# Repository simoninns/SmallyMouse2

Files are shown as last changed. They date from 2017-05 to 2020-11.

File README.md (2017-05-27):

## Synopsis

SmallyMouse2 is the AT90USB1287 firmware source code and KiCAD schematic/PCB design for the SmallyMouse2 project.

## Motivation

SmallyMouse2 is a project that creates a USB mouse adaptor for retro computers that use quadrature mouse input including the Acorn BBC Micro, Acorn Master series, Commodore Amiga, Atari ST, busmouse compatible computers and many more.  SmallyMouse2 provides both a generic mouse output header (for attaching mouse to retro computer cables) and an IDC connector suitable for use with Acorn 8-bit user-ports.  SmallyMouse2 also features a configurable quadrature rate limiter that prevents VIA overrun when in use with slower 8-bit machines.

SmallyMouse2 supports both JTAG and USB bootloader programming.  The AT90USB1287 is pre-programmed by Atmel with the (FLIP) DFU bootloader; this bootloader is recognised by Atmel Studio as a programming device and can be used to flash the firmware to the board.

## Installation

Note: This is an Atmel Studio 7 project that can be loaded and compiled by the IDE

Please see http://www.waitingforfriday.com/?p=827 for detailed documentation about SmallyMouse2

## Author

SmallyMouse2 is written and maintained by Simon Inns.

## License (Software)

    SmallyMouse2 is free software: you can redistribute it and/or modify
    it under the terms of the GNU General Public License as published by
    the Free Software Foundation, either version 3 of the License, or
    (at your option) any later version.

    SmallyMouse2 is distributed in the hope that it will be useful,
    but WITHOUT ANY WARRANTY; without even the implied warranty of
    MERCHANTABILITY or FITNESS FOR A PARTICULAR PURPOSE.  See the
    GNU General Public License for more details.

    You should have received a copy of the GNU General Public License
    along with SmallyMouse2. If not, see <http://www.gnu.org/licenses/>.

## License (Hardware)

Both the schematic and the PCB design of SmallyMouse2 (i.e. the KiCAD project and files) are covered by a Creative Commons license; as with the software you are welcome (and encouraged!) to extend, re-spin and otherwise use and modify the design as allowed by the license.  However; under the terms of the Attribution-ShareAlike 4.0 International (CC BY-SA 4.0) license you are required to release your design (or redesign) under the same license.  For details of the licensing requirements please see <https://creativecommons.org/licenses/by-sa/4.0/>

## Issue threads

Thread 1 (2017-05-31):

Spurious button presses on Acorn BBC Master

simoninns, 2017-05-31:
The device initialises with all three mouse buttons in the 'low' state.  Once the first USB report is received the buttons go into the 'high' state (since the mouse buttons are active low).  This causes multiple button presses to be received until the mouse is moved for the first time.  The initial state of the button signals should be high to prevent this.

simoninns, 2017-05-31:
Fixed and tested in last commit.

Closed 2017-05-31.

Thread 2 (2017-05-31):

Slow movement sometimes causes inverse quadrature movement

simoninns, 2017-05-31:
Moving the mouse very (very) slowly can sometimes cause inverse motion.  Observed on a 32-bit Acorn A440/1 machine (host-powered)

simoninns, 2017-05-31:
Fixed and tested in last commit.

Closed 2017-05-31.

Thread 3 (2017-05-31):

Which retro computers have been tested against the v1.1 release

simoninns, 2017-05-31:
Which retro computers are tested and confirmed as working with the v1.1 firmware release of SmallyMouse2?

simoninns, 2017-05-31:
The following retro computers are confirmed as working correctly with the v1.1 release of SmallyMouse2 so far:

Acorn BBC Micro Model B
Acorn Master Turbo
Acorn Archimedes A440/1
Acorn RISC PC 600

simoninns, 2017-06-04:
Tested and working with a Commodore Amiga A600.  Cable details soon.

simoninns, 2017-06-05:
Commodore Amiga A600 now confirmed (diagram added to project page).  Atari 520ST also confirmed (with diagram) - Testing submitted by Bas of BetaGamma Computing

simoninns, 2017-06-20:
Sinclair PC200 tested and confirmed.  Note from user:

Yes no problem. The PC200, Amstrad PC20 and some early Amstrad PCs have the opposite connector gender to the norm so it may be worth mentioning that.
1. X1
2. X2
3. Y1
4. Y2
5. n/c
6. LB
7. 5v
8. GND
9. RB

I also use Olivetti Prodest PC1 but have not confirmed SmallyMouse2 with it yet.
1. RB
2. LB
3. X1
4. Y2
5. 5v
6. Y1
7. X2
8. GND
9. GND (needed, or the PC1 assumes a joystick is connected).

simoninns, 2017-06-20:
Confirmed by a user to work with Acorn A3010 (same pin out as A440/1)

simoninns, 2018-08-26:
This issue is no longer required.

Closed 2018-08-26.

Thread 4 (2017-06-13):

Add USB joystick support?

simoninns, 2017-06-13:
It should be possible to add USB joystick support; most retro computers place the axis movement on the same pins as the USB mouse quadrature (X1, X2, Y1 and Y2) and use the mouse button inputs for the fire switches.

Firmware would need to be enhanced to support both mouse and gamepad HID and auto-switch depending on the connected USB device.

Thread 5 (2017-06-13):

Add report based HID mouse including scroll wheel support?

simoninns, 2017-06-13:
It should be possible to add scrollwheel support by outputting the scroll wheel quadrature between the current mouse X and Y outputs.  On the Amiga (using the wheelbusmouse software in workbench) this seems to be supported by outputting the horizontal scroll wheel on X1 and Y1 and the vertical scroll wheel on X2 and Y2 (although I haven't found any clear documentation). It's not clear from the existing (Amiga) software implementations how this is done right now (so the existing drivers may not support it).

The down-side to scroll wheel support is that the firmware cannot use the (very universal) boot-protocol for communicating with the mouse and must use the full report interface instead.  Some preliminary testing has shown this can be problematic since USB mice are not always really USB mice... For example the Logitech unifying receiver mice start in a standard mouse boot-protocol but do not support the standard reports-based communication (i.e. they are not really USB mice).  This could be very confusing to users as certain mice may not work.

It might be possible to solve this by using a fall-back mechanism where the firmware drops back to the boot-protocol if report based enumeration fails.  Needs some more experimentation to see if LUFA can be made to support such logic.

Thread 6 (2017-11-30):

Amiga 1200 doesn't detect right mouse button press

Septercius, 2017-11-30:
I'm trying to get the SM2 to work with an Amiga 1200 (revision 2B motherboard).  The interface does not detect a right mouse button click (left button and movement are fine).  Using the same setup on an Atari ST (swapping the X2/Y2 over) works without problem.

Using a multimeter, I tested the change in voltage that happens when a mouse button is pressed.  For the left button, the reading goes all the way down to 0V (from 5V).  For the right button, it goes to 0.3V and hovers around there.  If I disconnect the interface from the computer, the voltage does go to 0V when the button is pressed.

It seems that certain Amigas have this problem with other USB mouse adapters:

http://www.amibay.com/showthread.php?53905-Amiga-1200-USB-Mouse-adapter-No-Right-Mouse-button

Certain adapters claim to solve the issue (though it's not stated how):

https://www.ebay.co.uk/itm/MKIV-Amiga-USB-mouse-adapter-RIGHT-MOUSE-BUTTON-FIX/121715285463

Some people suggest that you need an external transistor somewhere:

http://eab.abime.net/showthread.php?t=64460

Is there a fix that can be made (e.g. by building a small circuit sitting between SM2 and computer) that will resolve this?

simoninns, 2017-11-30:
That's odd (very technical response, I know :) )...  Well, since the microcontroller is pulling up the lines to 5Vs it is most likely caused by the level not dropping all the way to 0V when the button is 'pressed' - this could only be caused by a very poor design in the host computer itself.  Simply placing a 4K7 resistor between the button signal and ground should cure the problem (4.7Kohms should be high enough to do the trick without 'straining' the internal pull-up).

If the BBC micro header is unpopulated, you could place the resistor there; otherwise you could solder it to the underside of the board (make sure the leads are insulated and don't cause any shorts).

Can you try this and see if it works?  If so please report back so I can update the project information and, thanks for reporting this!

Septercius, 2017-11-30:
Thanks for the response!  I'm currently using the 10-pin header, not the Beeb header.  The 5V pin and the 0V next to it are connected to a 5V PSU (2A, I think).  The rest of the pins are connected to a cable that leads to the standard 9-pin port on the back of the computer.  Just to be absolutely sure: I should leave this as it is and place the resistor in parallel, across the RB and 0V lines?  I've attached (I hope) a quick mock-up schematic that illustrates what I think I need to do.  Could you confirm I'm on the right track, please?  (I'd prefer not to blow anything up!).

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

simoninns, 2017-11-30:
Exactly right.  The same pins (RB and 0V) are exposed both on the 10-pin header and the 2 row IDC header for the BBC micro; if you simply trace the connections (using your multimeter) you could simply hook the resistor up using the holes for the IDC (but how you connect it isn't important, as long as it's between the RB and 0Vs) - it was just a suggestion.

Septercius, 2017-12-01:
Unfortunately wiring up the 4.7K resistor across the RB and 0V pins didn't make any difference.  The voltages were still 5V (button released) and 0.3V (button pressed).  I checked the circuit by touching both legs of the resistor together (I'd wired it in using some probes) and the computer acted as if the button was held down.

I also tried the next size up of resistor that I could find - 10K: same result.

simoninns, 2017-12-01:
Is there an accurate schematic of the motherboard for the version of Amiga you have?  If you could point me to it perhaps I can figure out what's going on.  There has to be a reason for it not working like this and, if I can figure that out, I could most probably suggest a better workaround.

Septercius, 2017-12-01:
There's some here:

http://www.amigawiki.de/doku.php?id=en:service:schematics

My motherboard is a revision 2B, so presumably it's version 2 of the schematic.

simoninns, 2017-12-02:
Pin 9 of the DSUB (RB) is connected to P0Y/P1Y of the 'PAULA' chip.  Since these are market 'POT0Y and POT1Y' it's safe to assume the chip is acting as an ADC.  The 'middle' button is connected the same way (although I would presume this isn't in use - but it would be failing in the same way).  All of the other lines are connected via a 74LS166 (an 8-bit shift register) which explains the difference.

The software must be expecting the ADC to read a very low value which is basically a bug in the mouse driver...  it should follow the TTL rules (anything below 0.8V should be considered a zero).

I'll have a look at how to solve this and post back.

simoninns, 2017-12-02:
The best thing I can think of (and I have no way to test as I don't have any Amigas) is to use a non-inverting voltage follower on the RB pin.  You can form this circuit with 2 resistors and a transistor (I think a normal small signal NPN will do it, but a MOSFET would provide more range).  If you could try the following circuit it should solve the issue:

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

Septercius, 2017-12-02:
I'll give it a whirl and see what happens, though I'll need to order some bits first.

Looking at the RS web site, there are lots of different BC547 transistors out there:

https://uk.rs-online.com/web/c/semiconductors/discrete-semiconductors/bipolar-transistors/?searchTerm=bc547

Does it matter which one I use?  The main difference I can spot (other than physical size) is in "Minimum DC Current Gain" (whatever that means).

simoninns, 2017-12-02:
The transistor probably doesn't matter too much as long as it's NPN.  I'd go for the 547B, although if you have a BC337 handy, it would probably work too.  Although the configuration is a 'voltage follower' the input to the base of the transistor is either 0V or 5V, so it's just swinging from min to max, so the details of the transistors finer qualities shouldn't make too much difference.

Basically the circuit should work like this:

If RB_in is 0V power cannot flow from the collector (pin 1) to the emitter (pin 3) of the transistor so the circuit takes the path of least resistance to ground.  If RB_out is 5V then power flows through the transistor making RB_out 5Vs.

The 10K resistor acts to limit the current draw from the microcontroller and the 4K7 pulls RB_out to 0V when the transistor is 'closed'.

The downside of a transistor is that it's not a 'perfect' switch, so it will never be truly 5V or 0Vs... the better the transistor - the closer it gets to being a switch (with MOSFET transistors being best at this).  Since the resistor is on the ground-side of the transistor it should present a much better 'ground' to the Amiga's ADC than the microcontroller pin... Thereby solving the issue...  (I hope! :) )

Septercius, 2017-12-16:
I finally found time to try the suggested circuit.  The 5V and 0V lines are connected to a separate 5V PSU.

The voltage is 4.44V if the right mouse button is pressed; if I press the button, it reduces to 3.85V, not 0V.  I have checked my circuit and can't see anything amiss.  If I connect everything as it was before (i.e. without the circuit), I see the previous behaviour (5V on not pressed, 0.3V on pressed) and all the other mouse functions work correctly.

simoninns, 2017-12-16:
Can you try increasing the value of the 4K7 resistor (10K, 100K, 1M) and see what effect it has?  If nothing works let me know and I'll try to find some time to set it up on the breadboard and look at what's going on.

snnsyhn, 2019-09-06:
Thank you.
I replaced the PAULA and the right mouse button problem solved.

simoninns, 2019-09-06:
Sounds like the root cause of this issue is identified; and the SM2 is functioning correctly.  Thanks for the feedback, I'll close this issue for now then,

gianlucarenzi, 2019-09-06:
I changed PAULA too, and it worked for me. As soon the board was in the customer's side, the problem persists. I had no time to check it out again... sorry. But I suppose something weird who breaks PAULA from the mouse port. I dunno.

ChuckyGang, 2020-01-31:
https://www.tsb.space/knowledge-base/amiga-1200-right-mousebutton-does-not-work/

JaneDoe649, 2020-07-19:
I had the same issue: the right mouse button did not respond when using the Smally Mouse. Apparently Paula's internal pull up resistor has a very low value which induces a current of almost 20mA when the level on Pot0X is set at 0V. Apparently the microcontroller cannot absorb it which causes too much voltage at the input of Paula to detect level 0.

I solved the problem by connecting the PC6 and PC7 pins together and modifying the declaration of the right button like this: #define RB ((1 << 6) | (1 << 7))

When the right button is pressed the two lines PC6 and PC7 drain the current and level 0 is well detected by Paula.

Closed 2019-09-06.

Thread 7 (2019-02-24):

Atari ST some problems

pazuzu72, 2019-02-24:
Hello everyone, on the **Amiga** it works very well (**500**, **600**, **1200**). On **Atari 1040 STE** (the only one I have available) has some problems. If I move the mouse too fast, it does not seem to be behind the speed and resets the pointer arrow position. Even setting the jumper on **slow**.

Can someone confirm or not the same problem?

dh219, 2019-12-06:
Yes, I can confirm. The ST range seems particularly sensitive to too high stimulus -- I can reproduce a similar effect on my 90s ball mouse by spinning the rollers with my finger.

The same problem is very hard to replicate on my Archie A3000, so I think it might be an Atari phenomenon and might explain why my TOM2 has such a low max speed in ST mode.

I'll try to have a dig in the firmware and see if I can improve it a bit.

dh219, 2019-12-31:
I've made some changes to my fork of the firmware that I think overcomes this issue -- firstly it looks like the Atari range can't handle polling rates over about 500Hz. Setting the rate limit to 500 solves the jumping cursor issue.

Also I've added a DPI scaler parameter that will basically scale down the effective DPI of the mouse as modern mice are far too high by default. I find a setting of 2 or 3 is good for modern 'slow' mice. 4 is about right for faster ones.

If you have the means to recompile and flash the firmware, have a look on my fork:- https://github.com/dh219/SmallyMouse2

pazuzu72, 2020-01-05:
Great! I have tried your version. I set the variable to 3 and it works great on 8 bit atari too. It is also better on amiga. Thank you :-)

simoninns, 2020-02-08:
In the V1.2 release I have added an additional 'jumper' configuration to turn on DPI divider support (which, by default divides by 2).  I have also lowered the quadrature limit when the SLOW header is used.  The DPI divider jumper should be placed between D7 and 0V on the expansion header which was previously a general purpose GPIO pin.

Closed 2020-02-08.

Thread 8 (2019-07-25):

At least RMB need to be open collector output

TzOk83, 2019-07-25:
Actually all outputs should be open-collector type, but on Atari ST the right mouse button is a must, as in other case it will conflict with a joystick fire button (they are shorted together on Atari side).

simoninns, 2019-07-26:
Can you elaborate more about the use-case here as I'm not really sure what your issue description is trying to solve.  This can't be a 'must' since there are many people using SM2 with Atari STs and it works.  What is the actual issue you are testing in order to reach your conclusion?

TzOk83, 2019-07-30:
This is a formal requirement of a mouse/joystick port - all outputs should be open-collector type (either in high impedance, or shorted to ground). In most cases it will work with a normal output, but problem will arise when you will try to use mouse on port 0 and joystick on port 1. Right mouse button on port 0 (pin 9) is connected together with a fire button on port 1 (pin 6). All signals are active low, so at idle they are held high (+5V). When you press fire on the joystick, the pin 9 of port 0 is directly shorted to ground, while on the same time SM2 tries to hold this pin high. In most cases it will work, but stressing the PC6 pin over its limits, and unnecessarily drawing over 20mA. Microswitch based joysticks will work fine, but some universal Atari/CPC or game-pads with rubber switches - won't due to high closed switch resistance.

dh219, 2019-12-06:
Can confirm what TzOk83 says. At least on the ST pressing fire on joystick 1 causes a short in the SmallyMouse2 with stock firmware. I've instigated a fix (for buttons only) in my fork. I'm not really familiar enough with Git to know how to submit a change to your repo for that file only. The diff is small and visible here, however, if you're interested: https://github.com/dh219/SmallyMouse2/commit/803f7c1757fec1a24074387a8cf2013e2163f189

Regards.

TzOk83, 2019-12-07:
@dh219 You should have created a Pull Request to the Master branch of the original project in order to integrate your patch with it.

simoninns, 2020-02-08:
In the V1.2 release I have added support for open-collector mouse buttons for all 3 buttons (as it shouldn't have any negative effects on other machines) - I've tested it with a BBC Micro and an Acorn Archimedes and it functions fine.

Closed 2020-02-08.

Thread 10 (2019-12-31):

Small 'direction lag' upon change of mouse movement direction.

dh219, 2019-12-31:
Symptom can be demonstrated on stock firmware:

* Switch to a low screen resolution (not necessary, but makes visualising it easier)

* Slowly move the mouse pointer left, right, up or down.

* Stop

* Slowly move the mouse pointer in the opposition direction, right, left, down or up.

> The initial movement of the mouse will be the first direction rather than the second.

This makes delicate selection difficult -- important in lower resolutions. I can reproduce this on Atari and Acorn hardware.

Can anyone else confirm this? Can anyone suggest where in the firmware to look for this 'direction lag'?

Regards,

DH.

simoninns, 2020-02-08:
This was a very well spotted bug :)  Took me quite a while to work out what was causing it...  Turns out that the quadrature phase was not being reset when the mouse changed direction, so for the tiny part of the phase left over the host computer didn't see the direction change.  In the V1.2 firmware the quadrature phase is reset as soon as there is a change of direction, which solves this issue (at least it does on the Acorn Archimedes A310/1 that I tested it on).

dh219, 2020-05-03:
Hi Simon,

Thanks for looking into this and deploying a proposed fix. Unfortunately the fix appears to be worse than the cure when tested on my Falcon.

With both the divisor (another requested feature added -- thanks) and the rate limiting (now defaulting to 500 -- thanks again) disabled to avoid any cross contamination with other new features, the quadrature output now seems to simply drop a lot of movement at low speed resulting in very strange jerkiness. Very occasionally some directional lag is still seen.

I've been trying to understand the effect the mouseEncoderPhaseX/Y=0 lines should have, but can't see how setting those when there is no movement should fix the original problem. Indeed, commenting them out restores behaviour to that of the 2017 variant, so I can see they're the source of this new behaviour.

From what I can understand, changing mouse direction should just change the direction of the quadrature state rather than starting again from zero, so I'm not sure this is the right place to address the bug.

I've put together a small video demonstrating the effect. Apologies for the mobile-pointing-at-a-screen quality.

[https://youtu.be/rnZ-SXimxc0](url)

simoninns, 2020-07-30:
I've reimplemented the fix in (what I think) is a more logical way.  I don't see any lag on my Archimedes A440/1; can you test the latest git commit @dh219 and let me know if it solves the issues for you?

dh219, 2020-11-08:
> I've reimplemented the fix in (what I think) is a more logical way. I don't see any lag on my Archimedes A440/1; can you test the latest git commit @dh219 and let me know if it solves the issues for you?

Hi @simoninns ,

Apologies for the long delay in getting back to you on this -- I blew up my unit and it's taken me this long to build a new one!

On the face of it, this seems to work beautifully compared to the previous releases. It's obviously more noticeable in lower resolutions so I've done some extensive testing at 320x200 (by playing Lemmings -- the test of champions) and all seems well here.

I don't know if you're interested in collecting known good settings, but FWIW, I found a DPI divisor of 3, a rate limit of 400 and a buffer limit of 400 produces very usable results on the Atari ST range with my set of cheap Amazon laser mice. I haven't tested on my A3000 yet, but that should behave like your A400 and be generally far more forgiving of higher rates.

Many thanks again and sorry for the delayed response.

DH.

Closed 2020-11-08.

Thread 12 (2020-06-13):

When moving mouse very slowly point stops moving.

xwildx, 2020-06-13:
Standard SmallyMouse2 Board
V1.2 Firmware
Amiga 500 Rev5 motherboard
When moving the mouse very slowly the point stops moving. If you speed up mouse movement a little pointer moves normally. This is only a small issue. but the problem becomes much worse when the right mouse button is pushed and held. Making it difficult to select menu items.

xwildx, 2020-06-14:
Did some more testing and found the following:

Commenting out the following 2 lines in the code.
mouseEncoderPhaseX = 0
mouseEncoderPhaseY = 0

Fixes the problem of the mouse stopping while moving very slowly. Of course this reintroduces the directional lag issue reported by dh219. I find this a much less annoying issue.

As for the RB issue. This looks to be something more problematic. I rewired  the MB to pin 9 (RB) input on the Amiga. So I'm using the MB on the mouse as the RB on the Amiga. (ie I swapped Pin 6 and 7 on the universal output connector).

So the MB acts like the RB, as far as the Amiga is concerned. This works normally and mouse movement is not affected when the MB (acting as RB) is pushed and held.
But if I push and hold the actual RB the mouse movement is still affected. Even if I disconnect the RB output from the amiga.

So it's not a problem with my Amiga hardware.

I have also tried a number of different mice. Both wired and wireless. All exhibit the same behaviour.

Maybe a problem with the USB library??

xwildx, 2020-06-18:
I have changed some lines in the code so the MB now outputs on pin 6 port c on the AVR and the RB now outputs on pin 5 of port c.

So now the MB is output to the right mouse button input on the Amiga
and the RB is output to the middle mouse button input on the Amiga
(Basically the same thing I did above but this time i did it in software not hardware)

If the MB is pushed and held it acts as the RB (menu) on the amiga and works fine.
If the RB is pushed and held it acts as the MB (not really used) on the amiga and the mouse movement is affected.

So I looks like the problem is only with the RB.

Could someone confirm this?? If you push and hold the RB on the mouse and slowly move the mouse  at the same time does it make the mouse movement erratic?

I have built 2 SmallyMouse2 boards and both exhibit this behaviour.

simoninns, 2020-06-18:
Thanks for reporting the issue; I don't have an Amiga, but I will test this out once I have the opportunity and see if I can recreate the observed behaviour.

xwildx, 2020-06-19:
Thanks for looking into it. I have done a bit more testing.
I powered the SM2 from a 5V supply plugged in a mouse and connected an oscilloscope to the Y2 output on the universal output connector. Note the SM2 is not connected to my Amiga.

I then tried to move the mouse, as steadily as possible, in the "UP" direction and observed the waveform. While moving the mouse I then pushed the RB.

As you can imagine moving the mouse steadily enough to get a "clean" waveform is difficult. But when I push the RB I can see the waveform change.

From this
_____         _____
|         |        |         |
|         |____|         |____

To This
__                __
|  |                |  |
|  |________|  |________

If the pulse is at  +5V say for 20ms and at 0V for 20ms, when the RB is pushed it changes to about 5ms and 35ms.
So the pulse width is narrowing with the RB pushed but the frequency stays the same.
And the slower you go the narrower the pulses get. But only with the RB pushed. The LB and MB don't have this  problem.
I will try to film this and put a video on youtube over the weekend.
Will post a link when its up.

xwildx, 2020-06-21:
I have put up a short video showing a capture of my oscilloscope. It's a bit hard to see but at about 6 sec I push and hold the RB and you can see the pulses become shorter. Some  are down to about 5ms or so.  This is only one output but it's the same on all 4 outputs. If you pause the video at about 8.5 Sec you can see the short pulses.

At the end of the video there is a small clip showing the mouse movement. About half way up the screen I push the RB and the mouse stops moving.

https://youtu.be/6IHmSAWSCrc

If there is anything else I can so to help let me know.

simoninns, 2020-06-22:
I've confirmed that the right button issue is reproducible and I get the same issue as observed on my test board.

It looks like the slow movement and RB held issues are possibly unrelated (so should be two issue reports), but I'll leave them as one for now.

simoninns, 2020-07-30:
I've pushed a fix which I believe solves the observed problems; can you compile and flash the latest git commit and test?  Please let me know the result @xwildx

xwildx, 2020-08-01:
Flashed the latest commit and have been testing it. Can confirm the slow movement and RB held problems are fixed. Thank you for the effort.

simoninns, 2020-08-01:
Great, I'll put up a new release shortly then.  Thanks for the assistance with testing!

Closed 2020-08-01.

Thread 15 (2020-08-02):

Potential improvements/minor issues

simoninns, 2020-08-02:
(copied from email source)

There's a potential divide by zero.  I could see that causing jerky mouse at low movement rates since the counter will tend towards zero the slower it's moved, so more chances for an exception or whatever that MCU does in that case.

Change line 519:
from: timerTopValue = ((10000 / timerTopValue) / 64) - 1;

to:
if (timerTopValue > 0)
    timerTopValue = ((10000 / timerTopValue) / 64) - 1;
else
    timerTopValue = 155;

Also found another minor bug where it detects a change in direction starting in line 380

if (MouseReport.X > 0 && mouseDirectionX == 0) {
    mouseDistanceX = 0;
    mouseDirectionX = 1;
} else if (MouseReport.X < 0 && mouseDirectionX == 1) {
    mouseDistanceX = 0;
    mouseDirectionX = 0;
} else if (MouseReport.Y > 0 && mouseDirectionY == 0) {
    mouseDistanceY = 0;
    mouseDirectionY = 1;
} else if (MouseReport.Y < 0 && mouseDirectionY == 1) {
    mouseDistanceY = 0;
    mouseDirectionY = 0;
}

This should be split into 2 blocks, otherwise if both axis change direction at the same time the Y axis won't get reversed correctly until the next USB report, causing the Y axis to move wrong/jerky for a short while.

if (MouseReport.X > 0 && mouseDirectionX == 0) {
    mouseDistanceX = 0;
    mouseDirectionX = 1;
} else if (MouseReport.X < 0 && mouseDirectionX == 1) {
    mouseDistanceX = 0;
    mouseDirectionX = 0;
}

 if (MouseReport.Y > 0 && mouseDirectionY == 0) {
    mouseDistanceY = 0;
    mouseDirectionY = 1;
} else if (MouseReport.Y < 0 && mouseDirectionY == 1) {
    mouseDistanceY = 0;
    mouseDirectionY = 0;
}

simoninns, 2020-11-28:
Fixed in master

Closed 2020-11-28.

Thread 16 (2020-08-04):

Add binaries to latest release

tdaede, 2020-08-04:
v1.2 is missing a binary.

FWIW probably only the .hex or .bin files are enough for DFU purposes.

simoninns, 2020-08-04:
I noticed that recently :)  I'm just running through some testing (and there are a couple more pending fixes) ready for a 1.3 release (1.2 had a couple of noticeable bugs for Atari and Amiga users).

When I release 1.3 I will include the .hex and close this issue (just so I don't forget in the meantime).

Thanks for the report!

pazuzu72, 2020-11-09:
Hi, is there any news on version 1.3? I need to make a couple for atari and amiga.

simoninns, 2020-11-28:
V1.3 released including .hex firmware image

Closed 2020-11-28.

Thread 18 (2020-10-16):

Very slow on 8-bit (BBC micro) machine

JasonStonier, 2020-10-16:
Ok, firstly thanks for a great design and for making it open source.

Disclosure - this is the first time I have soldered surface mount, and the first time I've programmed a microcontroller, so a thousand things could be wrong! Built the board up, flashed ok (I think) with Atmel Studio, and installed to a BBC micro with appropriate support ROM.

My board is sub-populated, so without the quadrature header, or the generic header - only the SMT parts, the 2x13 pin box header for bbc - the SLW jumper (closed), and the two uC bootload and reset jumpers (open).

On the beeb, I have to move the mouse -really- slowly to get it to register properly - the SLW jumper makes no difference.

Any pointers on what I should focus on to find the issue? Thanks.

simoninns, 2020-10-17:
It's a pretty simple circuit, so it's likely one of three things.

Firstly check around the AVR chip pin to pin with a multimeter and make sure you have no shorts.

Secondly check the fuse settings of the AVR and make sure they are right and the AVR is running at the correct speed (this is very unlikely to be wrong if the USB mouse is working at all).

Finally check the Beeb... either plug in a known working board/mouse or, if possible, try your SmallyMouse2 in another Beeb.  There can be anything from dirty pins to semi-working buffer ICs in there.

JasonStonier, 2020-10-18:
Thanks for the reply Simon. So, no shorts - checked all that, and also re-flowed the solder and checked every component to ground/AVR pin. the beeb is -unlikey- to be the problem as I have a number of userport devices which all work ok. Without going through the exact pinouts, obviously this isn't definitive but it seems unlikely.

Fuse settings - I have only the most basic knowledge of programming micros - to flash the device I just loaded up your Atmel project in studio 7, compiled it, and flashed it to the chip. Is there any setup which needs to be done to the chip before flashing?

I have a few PCBs and I've just ordered a batch of micros to build them up, so it may turn out to still be my dodgy soldering - I'll let you know.

simoninns, 2020-10-18:
The fuse settings should be fine if you used studio 7.

On the Beeb; there is a very (very) small chance it could be the 6522 VIAs; there are two in the Beeb though, so just swap them over and see (sometimes the GPIOs are fine, but the timers go weird).

Other than that, the most likely thing is some kind of construction error; making another board and comparing is a easy test though since you are already doing that.

JasonStonier, 2020-11-02:
Again, thanks for the replies - made a second board and exactly the same symptoms. All buzzed out ok and no shorts, but still the problem that moving the mouse too fast causes the pointer to reverse direction and get very choppy on screen.  Really strange! I've buzzed the ribbon cable out too, and pin to pin it's fine, so the last remaining thing to check is the 6522s. I've tried with two different mice, but will gather a collection to see if it's some weirdness with especially high DPI or something (I doubt it though, they're both bog standard USB mice) - or the surface I'm using them on (again, doubt it as they work fine in Linux).

JasonStonier, 2020-11-02:
I'm going to hack about with the code a bit to force it into rate limiting regardless of the SLW jumper - might help start to identify where my problem is.

JasonStonier, 2020-11-03:
Spent an hour inexpertly playing with the code (really well-commented code, very readable even for me) - first thing is that the SLW jumper definitely is being recognised by the uC, so I played with the settings for Q_RATELIMIT and Q_BUFFERLIMIT and discovered that my beeb won't sample accurately at a rate above 300Hz. With rate = 300 and buffer = 100 the mouse movement is now working, but physically moving the mouse fast causes the pointer to slow down significantly showing that sample points are being missed. The effect is present at rates down to 200Hz, but below 250Hz the sampling is too slow to represent the mouse movement properly (a fast circle produces a square, for example).

Is this adding evidence to the problem being in the timing of my 6522s?

simoninns, 2020-11-03:
The 6522s in the Beeb are generally in sockets and can be easily swapped.  The best way to test if the 6522s are at fault is to spend 2 minutes swapping them over; just try that and see if the issue goes away - that way you will know if that is the cause of the issue rather than guessing.  If a chip is failing the symptoms can be completely random, so there is no other way to tell for sure.

JasonStonier, 2020-11-05:
Cheers Simon - I will do that next time I have my beeb open (it's in a custom case so not just as easy as taking the lid off). What's interesting is that it needs to be exactly 300Hz: 301Hz exhibits the behaviour, so it doesn't <feel> like a timing fault. Can I ask: when you've done your testing on a beeb, what ROM and software are you using? - I'm using the official AMX ROM amxmse316 and AMXSuperArt as the test bed. Just wondering if it could be a sampling issue in the software, rather than a hardware fault.

simoninns, 2020-11-05:
I've used both AMX ROMs and VFS ROMs during testing... However; if you consider that many hundreds of SmallyMouse2 devices have been made - and many of those are used with Beebs...  It's far more likely to be a fault local to your setup than the software - which is why swapping the 6522s is a good approach.  If this is hard to do, perhaps buying a SM2 from Ebay and testing it on your machine would be another quick way to see where the issue is.

JasonStonier, 2020-11-05:
Of course - totally get that, and I appreciate the level of support you've shown for what is, after all, given away for free :-)  I'm trying to understand the problem, as well as solve it. Thanks.

simoninns, 2020-11-28:
Closing issue; please open a new one if you track the cause of your observations (and it is a bug/something that need investigation)

Closed 2020-11-28.

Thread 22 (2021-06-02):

Accept input from multiple USB mice

Mellified, 2021-06-02:
I have my SmallyMouse2 connected to an Atari Jaguar via a DB9 to DB15 adapter. With the wireless USB dongle for my mouse attached directly to the SmallyMouse2 everything works as expected! However, when connecting through my USB KVM the SmallyMouse2 does not work. I assume this is because there are multiple USB devices connected: 2 mice and 2 keyboards. In Linux and Windows the default behavior when multiple USB HID mice are connected is to sum the inputs and move the cursor accordingly. I'd like to see SmallyMouse2 updated to do the same ideally.

simoninns, 2021-06-03:
Unfortunately acting as a hub and supporting multiple device types is not really practical as the on-board processor doesn't have the support capabilities.  SmallyMouse2 only supports a single USB HID mouse device via the USB port.

Closed 2021-06-03.

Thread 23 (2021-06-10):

fix for A1200 Rev 2B Amiga RMB

kipper2k, 2021-06-10:
After building and testing the smally mouse on Amigas i found that the Rev2B A1200 Amiga RMB did not work. the problem was identified as bad caps and non working Paula. There is someone on Ebay who is selling "fixed" adapters but as far as i can tell he has not released any details on how he done it.

 I believe i have fixed the problem by placing 2 mosfets in cascade from the chip to the RMB input. I will play around with the resistor values and do a little more testing and then i will release the mod here so all can benefit

Sgw32, 2022-10-12:
@kipper2k Thanks for the idea!
Does it work on Amiga 500?

kipper2k, 2022-10-12:
yah, works on all

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

kipper2k, 2023-07-18:
Forgot to add this, it is a render of how it looks on the motherboard.
There is a USB header so people can run a USB cable if they don't want to
use the actual USB plug,. below the Smally is my video Hybrid board which
you break off and an expansion board for IDE so people can mount it
wherever :)

Brian

Closed 2023-11-20.

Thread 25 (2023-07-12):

Use of Smally mouse on an Amiga motherboard

kipper2000, 2023-07-12:
Hi, I am designing an Amiga 500 motherboard and i would like to add the layout of your smally mouse to the motherboard. I have someone screaming at me that i am not allowed to do it. I will not add the chip for it, just the layout and am making the motherboard gerber free to use so people can do thir own boards,

 Can i have permission to add the schematic to the motherboard. A USB mouse is much better than the already mounted serial mouse.

Thanks

kipper2k

simoninns, 2023-07-17:
This is allowed as the board design is CC licensed - you can read about this in the README.md in the main repo.  Provided you are intending on releasing under the same share-alike license, there is nothing to discuss :)

The software is GPL, but as this is only on the AVR itself, it doesn't knock-on to anything else that might be in your project.

If you are not intending on publishing your schematics and board designs under an open license - then it's not allowed.  However, if this is just because you don't want to use sharealike CC and want to use another open license - just let me know what you are planning and I can provide written permission.

(sorry for slow response, I'm on vacation at the moment :) )

kipper2000, 2023-07-18:
Hi Simon,

Hope your holiday  is going well :). Thanks for the reply.  The overall
scope of my project is to design a  new SMD Amiga 500+ motherboard. I built
the first test board back in early 2021 and then priorities shiftd so it
has been shelved ever since.  The current version motherboard itself has
been tested with onboard Gotek, 2MB chip mem and a quadrom option that
allows a user to toggle up to 4 x 512MB Rom images using an Amiga warm
reset (remembering current selected rom on next reboot. There is no issue
using these addons..  The Smally board circuit is on the motherboard also,
(see picture)  I still need to verify the circuit.  1 question for the
outputs to the original mouse port, do i need to put diodes on to protect
the chip in the event someone uses the original mouse port ?

 I am also adding 8MB fastmem and IDE functions so people can use CF card,
SD, and HDD using one of my old designs (based on NedoPC way back in 2015).
I  have found a way to implement 1 of those cheap Chinese wifi/bluetooth
Sony PS2 joysticks. Basically I am trying to give the A500+ all the options
without all the plugins.

 My desire for this board is to release the Gerbers free, and allow people
to build their own. This way they can do the work and I am assuming it
would be considered personal use. I know that people will probably want to
build a few themselves at a profit but if you check ebay etc it is
happening with boards etc that are not supposed to be commercially sold.

I am including your updated Smally schematic that I did with Mike Stirling
(he was the real brain :). It fixes the RMB problem on one of the A1200
version motherboards. I removed the header for the Atari version as
obviously no need on this motherboard

 I will of course give you full credit shown on the motherboard with
description of your choice. and like i said it will be up to the end user
to supply/program the chip. Ultimately I would like to just have the Smally
circuit on the motherboard so people have the choice of whether to use the
serial port or USB.

Thanks for your time, let me know if you need more info and if you are ok
with what I would like to do.

Brian, (kipper2k)

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

simoninns, 2023-07-27:
I would prefer that you followed the CC ShareAlike license rules... the idea is that, just as you take my design and benefit from using it in your design, others can take your design and benefit from using it in theirs.  What you are proposing is freely using and extending my work into something which you then provide closed (gerbers don't count as they are not really possible to manipulate).

Provided you are not-for-profit; I will be flexible and state you have permission to incorporate the schematic from SmallyMouse2 - but please consider using a sharealike design so others can benefit from your work as you are from mine :)

Closed 2023-07-27.

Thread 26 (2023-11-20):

Newlink NLMS-222A USB Mouse not working

simoninns, 2023-11-20:
I got a report from Amiga Kit that the Newlink NLMS-222A wired USB mouse does not work with SmallyMouse2.

Adding this report to track the issue.

simoninns, 2023-12-07:
Linux output when mouse connected:

```
2023-12-07T07:23:56.782703+01:00 sehotitan01 kernel: [159117.006815] usb 1-5: new low-speed USB device number 6 using xhci_hcd
2023-12-07T07:23:56.946602+01:00 sehotitan01 kernel: [159117.170479] usb 1-5: New USB device found, idVendor=1c4f, idProduct=0034, bcdDevice= 1.10
2023-12-07T07:23:56.946619+01:00 sehotitan01 kernel: [159117.170487] usb 1-5: New USB device strings: Mfr=1, Product=2, SerialNumber=0
2023-12-07T07:23:56.946620+01:00 sehotitan01 kernel: [159117.170489] usb 1-5: Product: Usb Mouse
2023-12-07T07:23:56.946621+01:00 sehotitan01 kernel: [159117.170491] usb 1-5: Manufacturer: SIGMACHIP
2023-12-07T07:23:56.962561+01:00 sehotitan01 kernel: [159117.188269] input: SIGMACHIP Usb Mouse as /devices/pci0000:00/0000:00:01.2/0000:02:00.0/0000:03:08.0/0000:06:00.1/usb1/1-5/1-5:1.0/0003:1C4F:0034.000D/input/input32
2023-12-07T07:23:56.962565+01:00 sehotitan01 kernel: [159117.188391] hid-generic 0003:1C4F:0034.000D: input,hidraw8: USB HID v1.10 Mouse [SIGMACHIP Usb Mouse] on usb-0000:06:00.1-5/input0
```

simoninns, 2023-12-07:
IC in use is marked MX8733B and WS31007:

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

simoninns, 2023-12-07:
MX8733B Datasheet:

[MX8733B.pdf](https://github.com/simoninns/SmallyMouse2/files/13599857/MX8733B.pdf)

simoninns, 2023-12-07:
Console output:

```
SmallyMouse2 V1.3 - Serial SmallyMouse2 V1.3 - Serial debug console
(c)2017-2020 Simon Inns
http://www.waitingforfriday.com

Rate limit switch is OFF
DPI divide switch is OFF
USB Device attached
USB Device detached
USB Device attached

Device Enumeration Error!
 -- Error Code 1
 -- Sub Error Code 1
 -- In State 8
USB Device detached
```

simoninns, 2023-12-07:
Looks like the mouse IC is pretty buggy and doesn't like to enumerate... The timeout is currently 1000ms (1 second) - but setting the enumeration timeout to 10 seconds seems to make the device work...

Adding the following parameter to the makefile seems to do the trick:

-DHOST_DEVICE_SETTLE_DELAY_MS=10000

I don't think this is generally good though as it slows down the initial enumeration with all devices.  Need some more testing.

simoninns, 2024-01-21:
End-user not replying to request to test.  Closing case.

Closed 2024-01-21.

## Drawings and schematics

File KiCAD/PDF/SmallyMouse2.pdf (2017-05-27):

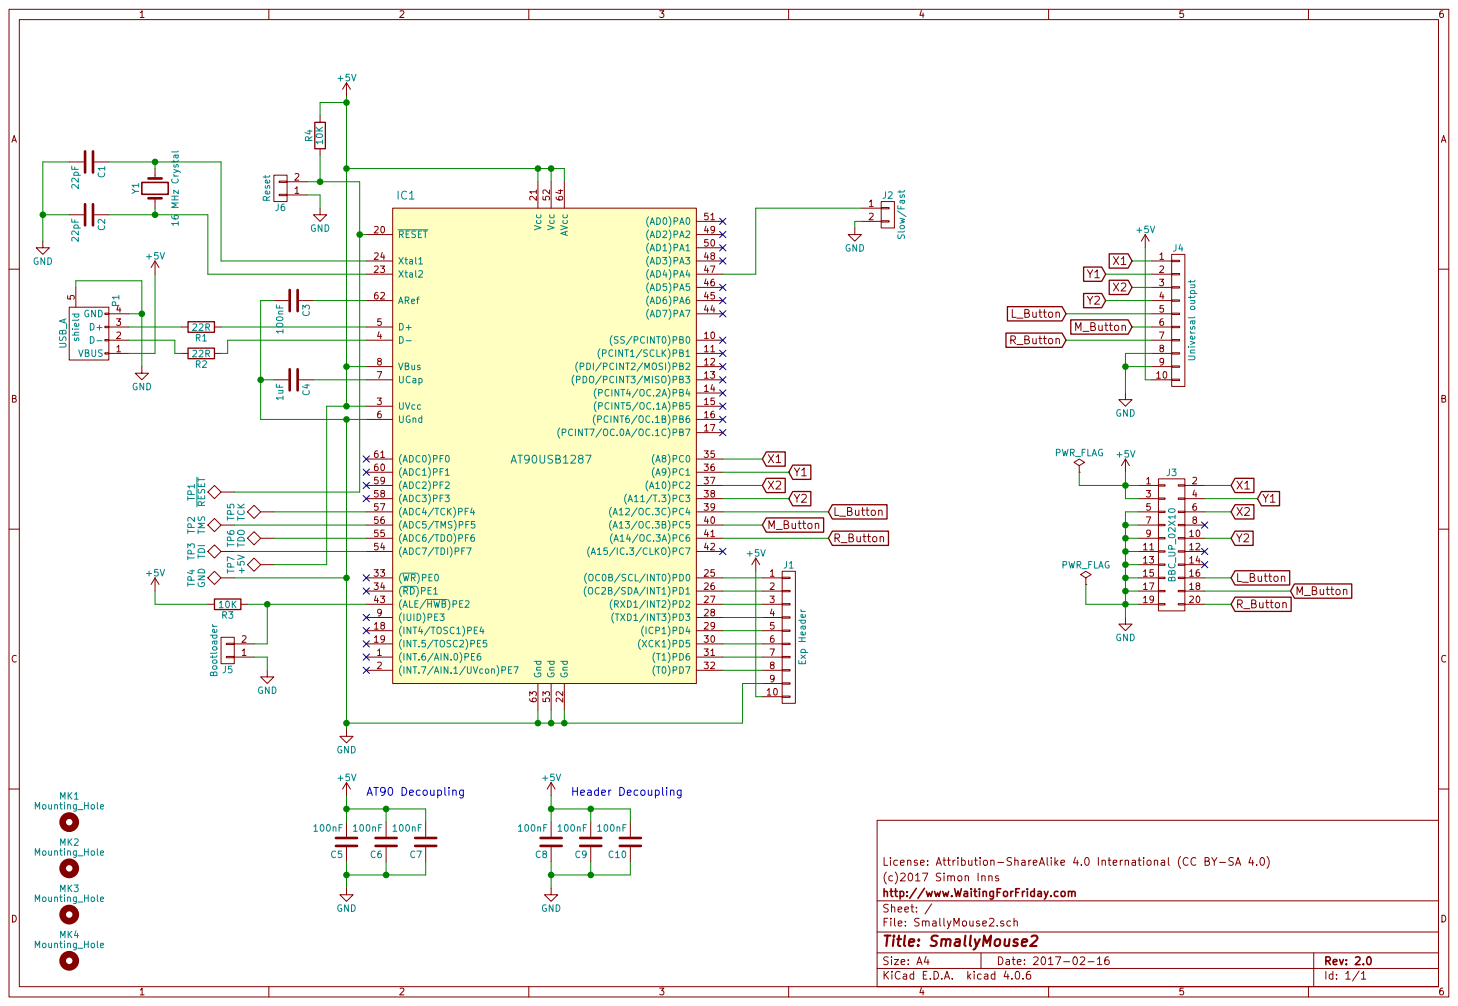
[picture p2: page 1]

(ADC0)PF0 61 (ADC1)PF1 60 (ADC2)PF2 59 (ADC3)PF3 58 (ADC4/TCK)PF4 57

(ADC5/TMS)PF5 56
(ADC6/TDO)PF6 55

(WR)PE0 33 (RD)PE1 34 (INT4/TOSC1)PE4 18 (INT.5/TOSC2)PE5 19

License: Attribution-ShareAlike 4.0 International (CC BY-SA 4.0)
(c)2017 Simon Inns
File: SmallyMouse2.sch Sheet: / http://www.WaitingForFriday.com

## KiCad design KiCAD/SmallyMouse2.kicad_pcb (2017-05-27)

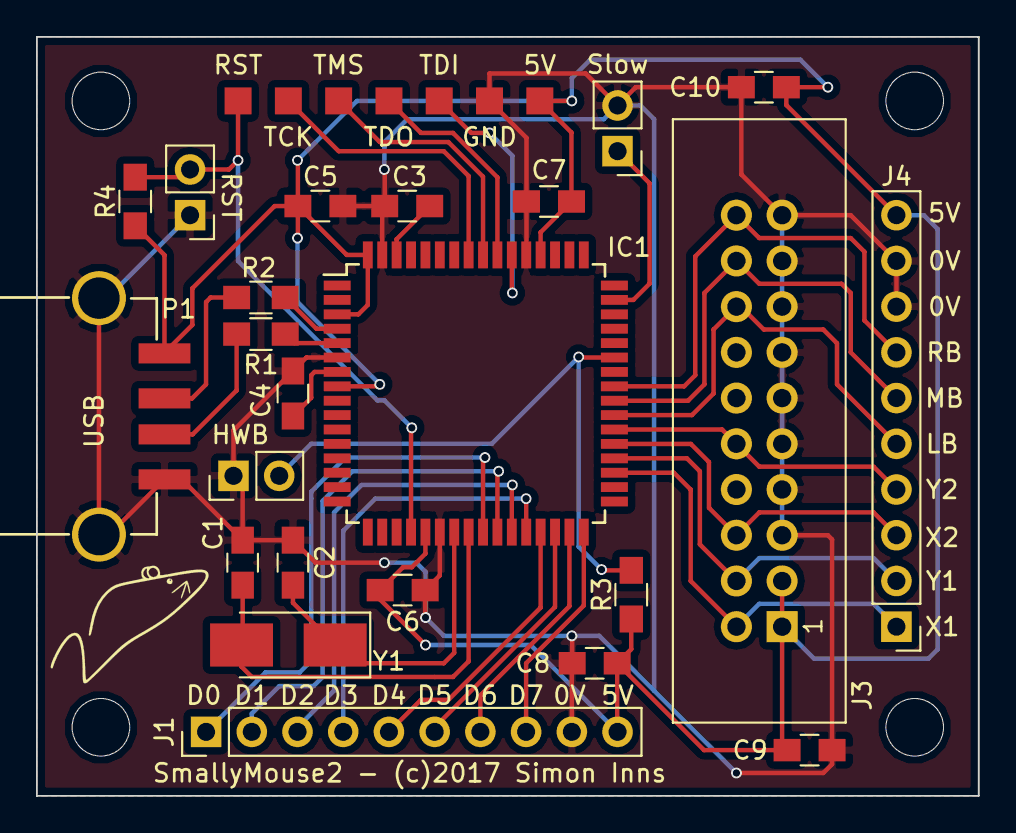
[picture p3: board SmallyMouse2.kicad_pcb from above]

Board: 2 copper layers, 52.3 x 42.2 mm, 34 parts (0 on the bottom side), 32 nets.

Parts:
5V: +5V; Measurement_Point_Square-SMD-Pad_Small
C1, C2: 22pF; C_0805_HandSoldering
C3, C5, C6, C7, C8, C9, C10: 100nF; C_0805_HandSoldering
C4: 1uF; C_0805_HandSoldering
GND: GND; Measurement_Point_Square-SMD-Pad_Small
IC1: AT90USB1287; TQFP-64_14x14mm_Pitch0.8mm
J1: Exp Header; Pin_Header_Straight_1x10_Pitch2.54mm
J2: Slow/Fast; Pin_Header_Straight_1x02_Pitch2.54mm
J3: BBC_UP_02X10; IDC_Header_Straight_20pins
J4: Universal output; Pin_Header_Straight_1x10_Pitch2.54mm
J5: Bootloader; Pin_Header_Straight_1x02_Pitch2.54mm
J6: Reset; Pin_Header_Straight_1x02_Pitch2.54mm
MK1, MK2, MK3, MK4: Mounting_Hole; MountingHole_3.2mm_M3_ISO14580
P1: USB_A; Amphenol_87583-2010BLF
R1, R2: 22R; R_0805_HandSoldering
R3, R4: 10K; R_0805_HandSoldering
RST: ~RESET; Measurement_Point_Square-SMD-Pad_Small
TCK: TCK; Measurement_Point_Square-SMD-Pad_Small
TDI: TDI; Measurement_Point_Square-SMD-Pad_Small
TDO: TDO; Measurement_Point_Square-SMD-Pad_Small
TMS: TMS; Measurement_Point_Square-SMD-Pad_Small
Y1: 16 MHz Crystal; Crystal_SMD_5032-2pin_5.0x3.2mm_HandSoldering

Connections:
+5V: 5V.1, C5.2, C6.2, C7.2, C8.2, C9.2, C10.2, IC1.3, IC1.8, IC1.21, IC1.52, IC1.64, J1.10, J3.1, J3.3, J4.10, P1.1, R3.2, R4.2
GND: C1.2, C2.2, C3.2, C4.2, C5.1, C6.1, C7.1, C8.1, C9.1, C10.1, GND.1, IC1.6, IC1.22, IC1.53, IC1.63, J1.9, J2.2, J3.5, J3.7, J3.9, J3.11, J3.13, J3.15, J3.17, J3.19, J4.8, J4.9, J5.1, J6.1, P1.4, P1.5
L_Button: IC1.39, J3.16, J4.5
M_Button: IC1.40, J3.18, J4.6
unnamed: C1.1, IC1.24, Y1.2
unnamed: C2.1, IC1.23, Y1.1
unnamed: C3.1, IC1.62
unnamed: C4.1, IC1.7
unnamed: IC1.4, R2.1
unnamed: IC1.5, R1.1
unnamed: IC1.20, J6.2, R4.1, RST.1
unnamed: IC1.25, J1.1
unnamed: IC1.26, J1.2
unnamed: IC1.27, J1.3
unnamed: IC1.28, J1.4
unnamed: IC1.29, J1.5
unnamed: IC1.30, J1.6
unnamed: IC1.31, J1.7
unnamed: IC1.32, J1.8
unnamed: IC1.43, J5.2, R3.1
unnamed: IC1.47, J2.1
unnamed: IC1.54, TDI.1
unnamed: IC1.55, TDO.1
unnamed: IC1.56, TMS.1
unnamed: IC1.57, TCK.1
unnamed: P1.2, R2.2
unnamed: P1.3, R1.2
R_Button: IC1.41, J3.20, J4.7
X1: IC1.35, J3.2, J4.1
X2: IC1.37, J3.6, J4.3
Y1: IC1.36, J3.4, J4.2
Y2: IC1.38, J3.10, J4.4

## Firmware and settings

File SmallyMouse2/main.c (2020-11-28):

/************************************************************************
	main.c

	Main functions
    SmallyMouse2 - USB to quadrature mouse converter
    Copyright (C) 2017-2020 Simon Inns

	This file is part of SmallyMouse2.

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
	Email: simon.inns@gmail.com

************************************************************************/

// Important notice:  If you port this firmware to another hardware design
// it *will be* a derivative of the original and therefore you must pay attention
// to the CC hardware licensing and release your hardware design as per the share-
// alike license.  Keep it open! ...and yes, that includes you Commodore chaps.

// System includes
#include <avr/io.h>
#include <avr/wdt.h>
#include <avr/pgmspace.h>
#include <avr/interrupt.h>
#include <avr/power.h>
#include <stdio.h>
#include <stdlib.h>

#include <util/delay.h>

// Note: SmallyMouse2 makes extensive use of the LUFA libraries:
//
// LUFA Library
// Copyright (C) Dean Camera, 2015.
// dean [at] fourwalledcubicle [dot] com
// www.lufa-lib.org

// Include LUFA libraries
#include <LUFA/Drivers/Misc/TerminalCodes.h>
#include <LUFA/Drivers/USB/USB.h>
#include <LUFA/Drivers/Peripheral/Serial.h>
#include <LUFA/Platform/Platform.h>

#include "ConfigDescriptor.h"
#include "main.h"

#define MOUSEX	0
#define MOUSEY	1

// Configuration ------------------------------------------------------------------------------------------------------

// Quadrature output frequency limit
//
// This setting limits the maximum frequency of the quadrature output towards the retro computer.
// If the rate of output is too high the retro computer cannot 'count' the input accurately and
// this causes spurious mouse movement.
//
// With no rate limit the quadrature output speed will reach a maximum of 3,906.25 Hz
// For 8-bit machines it is recommended that the speed doesn't exceed 500 Hz.  This limit is
// only applied if the 'slow' configuration jumper is shorted (i.e. on)
#define Q_RATELIMIT 500

// Quadrature output buffer limit
//
// Since the slow rate limit will prevent the quadrature output keeping up with the USB movement
// report input, the quadrature output will lag behind (i.e. the quadrature mouse will continue
// to move after the USB mouse has stopped).  This setting limits the maximum number of buffered
// movements to the quadrature output.  If the buffer reaches this value further USB movements
// will be discarded
#define Q_BUFFERLIMIT 300

// DPI Divider
//
// Some USB mice have very high DPI which causes the quadrature rate to be too high (making the
// mouse move too fast).  If the DPISW header is shorted the following constant will be used to 
// divide the DPI rate to slow things down.  2 or 3 are reasonable values.
#define DPI_DIVIDER 2

// Interrupt Service Routines for quadrature output -------------------------------------------------------------------

// The following globals are used by the interrupt service routines to track the mouse
// movement.  The mouseDirection indicates which direction the mouse is moving in and
// the mouseEncoderPhase tracks the current phase of the quadrature output.
//
// The mouseDistance variable tracks the current distance the mouse has left to move
// (this is incremented by the USB mouse reports and decremented by the ISRs as they
// output the quadrature to the retro host).
volatile int8_t mouseDirectionX = 0;		// X direction (0 = decrement, 1 = increment)
volatile int8_t mouseEncoderPhaseX = 0;		// X Quadrature phase (0-3)

volatile int8_t mouseDirectionY = 0;		// Y direction (0 = decrement, 1 = increment)
volatile int8_t mouseEncoderPhaseY = 0;		// Y Quadrature phase (0-3)

volatile int16_t mouseDistanceX = 0;		// Distance left for mouse to move
volatile int16_t mouseDistanceY = 0;		// Distance left for mouse to move

volatile uint8_t xTimerTop = 0;				// X axis timer TOP value
volatile uint8_t yTimerTop = 0;				// Y axis timer TOP value

// Interrupt Service Routine based on Timer0 for mouse X movement quadrature output
ISR(TIMER0_COMPA_vect)
{
	// Process X output
	if (mouseDistanceX > 0) {
		// Change phase and range check
		if (mouseDirectionX == 0) {
			mouseEncoderPhaseX--;
			if (mouseEncoderPhaseX < 0) mouseEncoderPhaseX = 3;
			} else {
			mouseEncoderPhaseX++;
			if (mouseEncoderPhaseX > 3) mouseEncoderPhaseX = 0;
		}
		
		// Set the output pins according to the current phase
		if (mouseEncoderPhaseX == 0) X1_PORT |=  X1;	// Set X1 to 1
		if (mouseEncoderPhaseX == 1) X2_PORT |=  X2;	// Set X2 to 1
		if (mouseEncoderPhaseX == 2) X1_PORT &= ~X1;	// Set X1 to 0
		if (mouseEncoderPhaseX == 3) X2_PORT &= ~X2;	// Set X2 to 0
		
		// Decrement the distance left to move
		mouseDistanceX--;
	}
	
	// Set the timer top value for the next interrupt
	OCR0A = xTimerTop;
}

// Interrupt Service Routine based on Timer2 for mouse Y movement quadrature output
ISR(TIMER2_COMPA_vect)
{
	// Process Y output
	if (mouseDistanceY > 0) {
		// Change phase and range check
		if (mouseDirectionY == 0) {
			mouseEncoderPhaseY--;
			if (mouseEncoderPhaseY < 0) mouseEncoderPhaseY = 3;
			} else {
			mouseEncoderPhaseY++;
			if (mouseEncoderPhaseY > 3) mouseEncoderPhaseY = 0;
		}
				
		// Set the output pins according to the current phase
		if (mouseEncoderPhaseY == 3) Y1_PORT &= ~Y1;	// Set Y1 to 0
		if (mouseEncoderPhaseY == 2) Y2_PORT &= ~Y2;	// Set Y2 to 0
		if (mouseEncoderPhaseY == 1) Y1_PORT |=  Y1;	// Set Y1 to 1
		if (mouseEncoderPhaseY == 0) Y2_PORT |=  Y2;	// Set Y2 to 1

		// Decrement the distance left to move
		mouseDistanceY--;
	}
	
	// Set the timer top value for the next interrupt
	OCR2A = yTimerTop;
}

// Main function
int main(void)
{
	// Initialise the SmallyMouse2 hardware
	initialiseHardware();
	
	// Initialise the ISR timers
	initialiseTimers();

	// Enable interrupts (required for USB support and quadrature output ISRs)
	sei();
	
	// Main processing loop
	while(1) {
		// Perform any pending mouse actions
		processMouse();

		// Process the USB host interface
		USB_USBTask();
	}
}

// Initialise the SmallyMouse2 hardware
void initialiseHardware(void)
{
	// Disable the watchdog timer (if set in fuses)
	MCUSR &= ~(1 << WDRF);
	wdt_disable();

	// Disable the clock divider (if set in fuses)
	clock_prescale_set(clock_div_1);

	// Set the quadrature output pins to output
	X1_DDR |= X1; // Output
	X2_DDR |= X2; // Output
	Y1_DDR |= Y1; // Output
	Y2_DDR |= Y2; // Output
	
	// Set quadrature output pins to zero
	X1_PORT &= ~X1; // Pin = 0
	X2_PORT &= ~X2; // Pin = 0
	Y1_PORT &= ~Y1; // Pin = 0
	Y2_PORT &= ~Y2; // Pin = 0
	
	// Set mouse button output pins open drain
	// (solves issues with some retro machines that
	// don't like 5V to be sources from the pins)
	LB_DDR &= ~LB; // 0 = input
	MB_DDR &= ~MB; // 0 = input
	RB_DDR &= ~RB; // 0 = input
	LB_PORT &= ~LB; // Pin = 0 (off)
	MB_PORT &= ~MB; // Pin = 0 (off)
	RB_PORT &= ~RB; // Pin = 0 (off)

	// Set the rate limit configuration header to input
	RATESW_DDR &= ~RATESW; // Input
	RATESW_PORT |= RATESW; // Turn on weak pull-up
	
	// Configure E7 on the expansion header to act as
	// DPISW (since it is easily jumpered to 0V)	
	DPISW_DDR &= ~DPISW; // Input
	DPISW_PORT |= DPISW; // Turn on weak pull-up
	
	// Initialise the expansion (Ian) header
	E0_DDR |= ~E0; // Output
	E1_DDR |= ~E1; // Output
	E2_DDR |= ~E2; // Output
	E3_DDR |= ~E3; // Output
	E4_DDR |= ~E4; // Output
	E5_DDR |= ~E5; // Output
	E6_DDR |= ~E6; // Output
	
	E0_PORT &= ~E0; // Pin = 0
	E1_PORT &= ~E1; // Pin = 0
	E2_PORT &= ~E2; // Pin = 0
	E3_PORT &= ~E3; // Pin = 0
	E4_PORT &= ~E4; // Pin = 0
	E5_PORT &= ~E5; // Pin = 0
	E6_PORT &= ~E6; // Pin = 0
	
	// Initialise the LUFA USB stack
	USB_Init();
	
	// By default, SmallyMouse2 will output USB debug events on the 
	// AVR's UART port.  You can monitor the debug console by connecting
	// a serial to USB adapter.  Only the Tx (D3 and 0V pins are required).
	
	// Initialise the serial UART - 9600 baud 8N1
	Serial_Init(9600, false);

	// Create a serial debug stream on stdio
	// Note: The serial UART is available on the 
	// expansion (Ian) header
	Serial_CreateStream(NULL);

	// Output some debug header information to the serial console
	puts_P(PSTR(ESC_FG_YELLOW "SmallyMouse2 V1.3 - Serial debug console\r\n" ESC_FG_WHITE));
	puts_P(PSTR(ESC_FG_YELLOW "(c)2017-2020 Simon Inns\r\n" ESC_FG_WHITE));
	puts_P(PSTR(ESC_FG_YELLOW "http://www.waitingforfriday.com\r\n" ESC_FG_WHITE));
	
	// Now report the status of the various configuration switches
	if ((RATESW_PIN & RATESW) == 0) puts_P(PSTR("Rate limit switch is ON\r\n"));
	else puts_P(PSTR("Rate limit switch is OFF\r\n"));
	if ((DPISW_PIN & DPISW) == 0) puts_P(PSTR("DPI divide switch is ON\r\n"));
	else puts_P(PSTR("DPI divide switch is OFF\r\n"));
}

// Initialise the ISR timers
void initialiseTimers(void)
{
	// The frequency of the reports from the USB mouse is about 100-125 Hz (i.e.
	// 100-125 reports per second).  Each report can indicate up to 127 position
	// movements in each direction (X & Y)
	
	// If we can receive 127 movements per report at a rate of 125 Hz
	// then the maximum movement per second is 100-125 Hz * 127 movements =
	// 12,700 - 15,875 movements per second (i.e. the quadrature output has 
	// to be 12,700 - 15,875 Hz to keep up)
	
	// The setting of the timers controls the maximum interrupt speed and 
	// therefore the maximum possible quadrature rate output.
	// 
	// Each movement unit reported by the USB device causes a single phase
	// change in the quadrature output (which means there is a 4:1 ratio
	// between the USB movement units and the quadrature movement output)
	
	// Timer0 and Timer2 are 8-bit timers.  Therefore the slowest interrupt
	// speed possible is 256 times the tick period and the fastest is a single
	// tick period.
	
	// Timer prescale is /1024 and the AVR clock speed is 16,000,000 Hz
	// 16,000,000 Hz / 1024 prescale = 15,625 ticks per second
	//
	// 1,000,000 uS per second / 15,625 ticks per second = 64 uS per tick
	//
	// 15,625 ticks (with a 4:1 ratio) means the maximum quadrature output
	// will be 3,906.25 Hz.

	// Configure Timer0 to interrupt (8-bit timer)
	OCR0A = 0; // In CTC mode OCR0A = TOP
	TCCR0A = (1 << WGM01); // Clear timer on compare match (CTC) mode
	TCCR0B = 5; //  CS02/CS01/CS00 = binary 101 = /1024 prescale
	TIMSK0 = (1 << OCIE0A); // Timer0 interrupt enabled
		
	// Configure Timer2 to interrupt (8-bit timer)
	OCR2A = 0; // In CTC mode OCR2A = TOP
	TCCR2A = (1 << WGM21); // Clear timer on compare match (CTC) mode
	TCCR2B = 7; // CS22/CS21/CS20 = binary 111 = /1024 prescale
	TIMSK2 = (1 << OCIE2A); // Timer2 interrupt enabled
}

// Read the mouse USB report and process the information
void processMouse(void)
{
	USB_MouseReport_Data_t MouseReport;
	bool limitRate = false;
	bool dpiDivide = false;
		
	// Only process the mouse if a mouse is attached to the USB port
	if (USB_HostState != HOST_STATE_Configured)	return;
	
	// Get the state of the rate limiting (slow) header
	if ((RATESW_PIN & RATESW) == 0) limitRate = true;
	
	// Get the state of the DPI divider header
	if ((DPISW_PIN & DPISW) == 0) dpiDivide = true;
	
	// Select mouse data pipe
	Pipe_SelectPipe(MOUSE_DATA_IN_PIPE);

	// Unfreeze mouse data pipe
	Pipe_Unfreeze();

	// Has a packet arrived from the USB device?
	if (!(Pipe_IsINReceived())) {
		// Nothing received, exit...
		Pipe_Freeze();
		return;
	}

	// Ensure pipe is in the correct state before reading
	if (Pipe_IsReadWriteAllowed()) {
		// Set USB report processing activity on expansion port pin D0
		// Note: This can be used to analyze the rate at which USB mouse
		// reports are received by measuring the rate using an oscilloscope
		// or frequency counter on D0
		E0_PORT |= E0; // Pin = 1
		
		// Read in mouse report data
		Pipe_Read_Stream_LE(&MouseReport, sizeof(MouseReport), NULL);
		
		// The USB mouse report contains 3 variables: button, X and Y
		//
		// Button is an 8-bit flag containing up to 5 button states:
		//   (LSB)1 = Left button
		//        2 = Right button
		//        4 = Middle button
		//
		// Note: Buttons are active low (i.e. 0 = pressed)
		//
		// X and Y indicate the number of steps the mouse moved since the
		// last report was sent.
		//
		// +X = Mouse going right
		// -X = Mouse going left
		// +Y = Mouse going down
		// -Y = Mouse going up
		//
		// X and Y have a range of -127 to +127
		
		// If the mouse movement changes X direction then disregard any remaining movement
		if (MouseReport.X > 0 && mouseDirectionX == 0) {
			mouseDistanceX = 0;
			mouseDirectionX = 1;
		} else if (MouseReport.X < 0 && mouseDirectionX == 1) {
			mouseDistanceX = 0;
			mouseDirectionX = 0;
		}
		
		// If the mouse movement changes Y direction then disregard any remaining movement
		if (MouseReport.Y > 0 && mouseDirectionY == 0) {
			mouseDistanceY = 0;
			mouseDirectionY = 1;
			} else if (MouseReport.Y < 0 && mouseDirectionY == 1) {
			mouseDistanceY = 0;
			mouseDirectionY = 0;
		}
		
		// Process mouse X and Y movement -------------------------------------
		xTimerTop = processMouseMovement(MouseReport.X, MOUSEX, limitRate, dpiDivide);
		yTimerTop = processMouseMovement(MouseReport.Y, MOUSEY, limitRate, dpiDivide);
		
		// Process mouse buttons ----------------------------------------------
		
		// Check for left mouse button
		if ((MouseReport.Button & 0x01) == 0) {
			// Open-drain
			LB_PORT &= ~LB;
			LB_DDR &= ~LB;
		} else {
			// Set to 0V
			LB_DDR |= LB; // 1 = output
			LB_PORT &= ~LB; // Button low
		}
			
		// Check for middle mouse button
		if ((MouseReport.Button & 0x04) == 0) {
			// Open-drain
			MB_PORT &= ~MB;
			MB_DDR &= ~MB;
		} else {
			// Set to 0V
			MB_DDR |= MB; // 1 = output
			MB_PORT &= ~MB; // Button low
		}
			
		// Check for right mouse button
		if ((MouseReport.Button & 0x02) == 0) {
			// Open-drain
			RB_PORT &= ~RB;
			RB_DDR &= ~RB;
		} else {
			// Set to 0V
			RB_DDR |= RB; // 1 = output
			RB_PORT &= ~RB; // Button low
		}
		
		// Clear USB report processing activity on expansion port pin D0
		E0_PORT &= ~E0; // Pin = 0
	}

	// Clear the IN endpoint, ready for next data packet
	Pipe_ClearIN();

	// Refreeze mouse data pipe
	Pipe_Freeze();
}

// Process the mouse movement units from the USB report
uint8_t processMouseMovement(int8_t movementUnits, uint8_t axis, bool limitRate, bool dpiDivide)
{
	uint16_t timerTopValue = 0;
	
	// Set the mouse movement direction and record the movement units
	if (movementUnits > 0) {
		// Moving in the positive direction
		
		// Apply DPI limiting if required
		if (dpiDivide) {
			movementUnits /= DPI_DIVIDER;
			if (movementUnits < 1) movementUnits = 1;
		}
		
		// Add the movement units to the quadrature output buffer
		if (axis == MOUSEX) mouseDistanceX += movementUnits;
		else mouseDistanceY += movementUnits;
	} else if (movementUnits < 0) {
		// Moving in the negative direction
		
		// Apply DPI limiting if required
		if (dpiDivide) {
			movementUnits /= DPI_DIVIDER;
			if (movementUnits > -1) movementUnits = -1;
		}
		
		// Add the movement units to the quadrature output buffer
		if (axis == MOUSEX) mouseDistanceX += -movementUnits;
		else mouseDistanceY += -movementUnits;
	} else {
		if (axis == MOUSEX) mouseDistanceX = 0;
		else mouseDistanceY = 0;
	}
	
	// Apply the quadrature output buffer limit
	if (axis == MOUSEX) {
		if (mouseDistanceX > Q_BUFFERLIMIT) mouseDistanceX = Q_BUFFERLIMIT;
	} else {
		if (mouseDistanceY > Q_BUFFERLIMIT) mouseDistanceY = Q_BUFFERLIMIT;
	}
	
	// Get the current value of the quadrature output buffer
	if (axis == MOUSEX) timerTopValue = mouseDistanceX;
	else timerTopValue = mouseDistanceY;
	
	// Range check the quadrature output buffer
	if (timerTopValue > 127) timerTopValue = 127;
	
	// Since the USB reports arrive at 100-125 Hz (even if there is only
	// a small amount of movement, we have to output the quadrature
	// at minimum rate to keep up with the reports (otherwise it creates
	// a slow lag).  If we assume 100 Hz of reports then the following
	// is true:
	//
	// 127 movements = 12,700 interrupts/sec
	// 100 movements = 10,000 interrupts/sec
	//  50 movements =  5,000 interrupts/sec
	//  10 movements =  1,000 interrupts/sec
	//   1 movement  =    100 interrupts/sec
	//
	// Timer speed is 15,625 ticks per second = 64 uS per tick
	//
	// Required timer TOP values (0 is fastest so all results are x-1):
	// 1,000,000 / 12,700 = 78.74 / 64 uS = 1.2 - 1
	// 1,000,000 / 10,000 = 100 / 64 uS = 1.56 - 1
	// 1,000,000 / 5,000 = 200 / 64 uS = 3.125 - 1
	// 1,000,000 / 1,000 = 1000 uS / 64 uS = 15.63 - 1
	// 1,000,000 / 100 = 10000 uS / 64 uS = 156.25 - 1
	//
	// So:
	//   timerTopValue = 10000 / timerTopValue; // i.e. 1,000,000 / (timerTopValue * 100)
	//   timerTopValue = timerTopValue / 64;
	//   timerTopValue = timerTopValue - 1;
	
	if (timerTopValue > 0) timerTopValue = ((10000 / timerTopValue) / 64) - 1;
	else timerTopValue = 0; // Avoid divide by zero
		
	// If the 'Slow' configuration jumper is shorted; apply the quadrature rate limit
	if (limitRate) {
		// Rate limit is on
		
		// Rate limit is provided in hertz
		// Each timer tick is 64 uS
		//
		// Convert hertz into period in uS
		// 1500 Hz = 1,000,000 / 1500 = 666.67 uS
		// 
		// Convert period into timer ticks (* 4 due to quadrature)
		// 666.67 us / (64 * 4) = 2.6 ticks
		//
		// Timer TOP is 0-255, so subtract 1
		// 10.42 ticks - 1 = 9.42 ticks
		
		uint32_t rateLimit = ((1000000 / Q_RATELIMIT) / 256) - 1;
		
		// If the timerTopValue is less than the rate limit, we output
		// at the maximum allowed rate.  This will cause addition lag that
		// is handled by the quadrature output buffer limit above.
		if (timerTopValue < (uint16_t)rateLimit) timerTopValue = (uint16_t)rateLimit;
	}
	
	// Return the timer TOP value
	return (uint8_t)timerTopValue;
}

// LUFA event handlers ------------------------------------------------------------------------------------------------

// Event handler for the USB_DeviceAttached event. This indicates that a device has been attached to the host, and
// starts the library USB task to begin the enumeration and USB management process.
void EVENT_USB_Host_DeviceAttached(void)
{
	puts_P(PSTR(ESC_FG_GREEN "USB Device attached\r\n" ESC_FG_WHITE));
}

// Event handler for the USB_DeviceUnattached event. This indicates that a device has been removed from the host, and
// stops the library USB task management process.
void EVENT_USB_Host_DeviceUnattached(void)
{
	puts_P(PSTR(ESC_FG_GREEN "USB Device detached\r\n" ESC_FG_WHITE));
}

// Event handler for the USB_DeviceEnumerationComplete event. This indicates that a device has been successfully
// enumerated by the host and is now ready to be used by the application.
void EVENT_USB_Host_DeviceEnumerationComplete(void)
{
	puts_P(PSTR("Getting configuration data from device...\r\n"));

	uint8_t ErrorCode;

	/* Get and process the configuration descriptor data */
	if ((ErrorCode = ProcessConfigurationDescriptor()) != SuccessfulConfigRead) {
		if (ErrorCode == ControlError) {
			puts_P(PSTR(ESC_FG_RED "Control Error (Get configuration)!\r\n"));
		} else {
			puts_P(PSTR(ESC_FG_RED "Invalid Device!\r\n"));
		}

		printf_P(PSTR(" -- Error Code: %d\r\n" ESC_FG_WHITE), ErrorCode);
		return;
	}

	// Set the device configuration to the first configuration (rarely do devices use multiple configurations)
	if ((ErrorCode = USB_Host_SetDeviceConfiguration(1)) != HOST_SENDCONTROL_Successful) {
		printf_P(PSTR(ESC_FG_RED "Control Error (Set configuration)!\r\n"
		                         " -- Error Code: %d\r\n" ESC_FG_WHITE), ErrorCode);
		return;
	}
	
	// HID class request to set the mouse protocol to the Boot Protocol
	USB_ControlRequest = (USB_Request_Header_t) {
			.bmRequestType = (REQDIR_HOSTTODEVICE | REQTYPE_CLASS | REQREC_INTERFACE),
			.bRequest      = HID_REQ_SetProtocol,
			.wValue        = 0,
			.wIndex        = 0,
			.wLength       = 0,
	};

	// Select the control pipe for the request transfer
	Pipe_SelectPipe(PIPE_CONTROLPIPE);

	// Send the request, display error and wait for device detach if request fails
	if ((ErrorCode = USB_Host_SendControlRequest(NULL)) != HOST_SENDCONTROL_Successful) {
		printf_P(PSTR(ESC_FG_RED "Control Error (Set protocol)!\r\n"
								 " -- Error Code: %d\r\n" ESC_FG_WHITE), ErrorCode);

		USB_Host_SetDeviceConfiguration(0);
		return;
	}

	puts_P(PSTR("USB Mouse enumeration successful\r\n"));
}

// Event handler for the USB_HostError event. This indicates that a hardware error occurred while in host mode.
void EVENT_USB_Host_HostError(const uint8_t ErrorCode)
{
	USB_Disable();

	printf_P(PSTR(ESC_FG_RED "Host Mode Error!\r\n"
	                       " -- Error Code %d\r\n" ESC_FG_WHITE), ErrorCode);

	while(1);
}

// Event handler for the USB_DeviceEnumerationFailed event. This indicates that a problem occurred while
// enumerating an attached USB device.
void EVENT_USB_Host_DeviceEnumerationFailed(const uint8_t ErrorCode,
                                            const uint8_t SubErrorCode)
{
	printf_P(PSTR(ESC_FG_RED "Device Enumeration Error!\r\n"
	                         " -- Error Code %d\r\n"
	                         " -- Sub Error Code %d\r\n"
	                         " -- In State %d\r\n" ESC_FG_WHITE), ErrorCode, SubErrorCode, USB_HostState);
}

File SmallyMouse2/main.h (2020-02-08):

/************************************************************************
	main.h

	Main functions
    SmallyMouse2 - USB to quadrature mouse converter
    Copyright (C) 2017-2020 Simon Inns

	This file is part of SmallyMouse2.

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
	Email: simon.inns@gmail.com

************************************************************************/

#ifndef _MAIN_H_
#define _MAIN_H_

// Hardware map

// Quadrature mouse output port
// Right mouse button
#define RB_PORT	PORTC
#define RB_PIN	PINC
#define RB_DDR	DDRC
#define RB		(1 << 6)

// Middle mouse button
#define MB_PORT	PORTC
#define MB_PIN	PINC
#define MB_DDR	DDRC
#define MB		(1 << 5)

// Left mouse button
#define LB_PORT	PORTC
#define LB_PIN	PINC
#define LB_DDR	DDRC
#define LB		(1 << 4)

// Y axis output
#define Y2_PORT	PORTC
#define Y2_PIN	PINC
#define Y2_DDR	DDRC
#define Y2		(1 << 3)

#define Y1_PORT	PORTC
#define Y1_PIN	PINC
#define Y1_DDR	DDRC
#define Y1		(1 << 1)

// X axis output
#define X2_PORT	PORTC
#define X2_PIN	PINC
#define X2_DDR	DDRC
#define X2		(1 << 2)

#define X1_PORT	PORTC
#define X1_PIN	PINC
#define X1_DDR	DDRC
#define X1		(1 << 0)

// Rate limit on/off switch (marked 'slow')
#define RATESW_PORT	PORTA
#define RATESW_PIN	PINA
#define RATESW_DDR	DDRA
#define RATESW		(1 << 4)

// Expansion (Ian) header
#define E0_PORT	PORTD
#define E0_PIN	PIND
#define E0_DDR	DDRD
#define E0		(1 << 0)

#define E1_PORT	PORTD
#define E1_PIN	PIND
#define E1_DDR	DDRD
#define E1		(1 << 1)

#define E2_PORT	PORTD
#define E2_PIN	PIND
#define E2_DDR	DDRD
#define E2		(1 << 2)

#define E3_PORT	PORTD
#define E3_PIN	PIND
#define E3_DDR	DDRD
#define E3		(1 << 3)

#define E4_PORT	PORTD
#define E4_PIN	PIND
#define E4_DDR	DDRD
#define E4		(1 << 4)

#define E5_PORT	PORTD
#define E5_PIN	PIND
#define E5_DDR	DDRD
#define E5		(1 << 5)

#define E6_PORT	PORTD
#define E6_PIN	PIND
#define E6_DDR	DDRD
#define E6		(1 << 6)


// E7 is now used as the DPISW header
#define DPISW_PORT	PORTD
#define DPISW_PIN	PIND
#define DPISW_DDR	DDRD
#define DPISW		(1 << 7)

// Function prototypes
void initialiseHardware(void);
void initialiseTimers(void);
void processMouse(void);
uint8_t processMouseMovement(int8_t movementUnits, uint8_t axis, bool limitRate, bool dpiDivide);

// USB callback event handlers (LUFA)
void EVENT_USB_Host_HostError(const uint8_t ErrorCode);
void EVENT_USB_Host_DeviceAttached(void);
void EVENT_USB_Host_DeviceUnattached(void);
void EVENT_USB_Host_DeviceEnumerationFailed(const uint8_t ErrorCode, const uint8_t SubErrorCode);
void EVENT_USB_Host_DeviceEnumerationComplete(void);

void ReadNextReport(void);

#endif

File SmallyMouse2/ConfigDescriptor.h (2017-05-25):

/*
             LUFA Library
     Copyright (C) Dean Camera, 2015.

  dean [at] fourwalledcubicle [dot] com
           www.lufa-lib.org
*/

/*
  Copyright 2015  Dean Camera (dean [at] fourwalledcubicle [dot] com)

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
  The author disclaims all warranties with regard to this
  software, including all implied warranties of merchantability
  and fitness.  In no event shall the author be liable for any
  special, indirect or consequential damages or any damages
  whatsoever resulting from loss of use, data or profits, whether
  in an action of contract, negligence or other tortious action,
  arising out of or in connection with the use or performance of
  this software.
*/

/** \file
 *
 *  Header file for ConfigDescriptor.c.
 */

#ifndef _CONFIGDESCRIPTOR_H_
#define _CONFIGDESCRIPTOR_H_

	/* Includes: */
		#include <LUFA/Drivers/USB/USB.h>

		#include "main.h"

	/* Macros: */
		/** Pipe address for the mouse data IN pipe. */
		#define MOUSE_DATA_IN_PIPE          (PIPE_DIR_IN | 1)

	/* Enums: */
		/** Enum for the possible return codes of the \ref ProcessConfigurationDescriptor() function. */
		enum MouseHost_GetConfigDescriptorDataCodes_t
		{
			SuccessfulConfigRead            = 0, /**< Configuration Descriptor was processed successfully */
			ControlError                    = 1, /**< A control request to the device failed to complete successfully */
			DescriptorTooLarge              = 2, /**< The device's Configuration Descriptor is too large to process */
			InvalidConfigDataReturned       = 3, /**< The device returned an invalid Configuration Descriptor */
			NoCompatibleInterfaceFound      = 4, /**< A compatible interface with the required endpoints was not found */
		};

	/* Function Prototypes: */
		uint8_t ProcessConfigurationDescriptor(void);

		uint8_t DComp_NextMouseInterface(void* CurrentDescriptor);
		uint8_t DComp_NextMouseInterfaceDataEndpoint(void* CurrentDescriptor);

#endif

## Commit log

2017-05-25 Added KiCAD schematic and PCB files
    KiCAD schematic and PCB files include gerber output for board
    fabrication
    [SmallyMouse2-B.Cu.gbl, SmallyMouse2-B.Mask.gbs, SmallyMouse2-B.SilkS.gbo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]
2017-05-27 Fixes to KiCAD project files and addition PDF of schematic
2017-05-27 Updated PCB board files with title and licensing information
    [SmallyMouse2.kicad_pcb]
2017-05-27 Updated readme with KiCAD project license details
2017-05-28 Major code rewrite
    Improved code overall for smoother quadrature output and better
    performance. Lots of fixes to the code in terms of making it easier to
    understand and easier to configure.
    [main.c, main.h]
2017-05-30 Rewrite of quadrature output routines
    Rewrite of quadrature output routines to make them smoother, more
    analogue in nature and also more accurate. Max hertz output is now
    correctly limited and the buffer limit and rate limit features have been
    improved
    [main.c, main.h]
2017-05-30 Corrections to ratelimit calculations
    Corrections to ratelimit calculations to ensure correct timing according
    the the rate limit hertz configuration setting. Previous version had a
    bug in the calculations. Also change quadrature output to default to 0
    when idle. This is to prevent SmallyMouse2 from supplying power to the
    host (when SmallyMouse is self-powered and the host is off).
    [main.c]
2017-05-31 Minor corrections to comments
    [main.c, main.h]
2017-05-31 Fixes for issues #1 and #2
    Fixes for issues #1 and #2. Inverted mouse buttons initialisation state
    and removed 'quadrature output reset' from interrupt code
    [main.c]
2020-02-08 Updated headers and added notice on hardware licensing for issue #9
    [main.c, main.h]
2020-02-08 Lowered rate limit and added DPI divider jumper on E7/0V of the expansion header - issue #7
    [main.c, main.h]
2020-02-08 Changed mouse button GPIOs to support open-drain - fix for issue #8
    [main.c]
2020-02-08 Fix for issue #10 - caused by lag in changing quadrature phase when reversing direction
    [main.c]
2020-02-08 Added comments around the phase reset to make it clearer
    [main.c]
2020-07-30 Bug fix for issue #12
    Solves issue with pointer motion when right button is held down
    [main.c]
2020-07-30 Fix for issue #10
    Changed the order in which new mouse motion is output; code now change phase first then outputs the phase to the IO
    [main.c]
2020-11-14 Fixes according to issue #15
    [main.c]
2020-11-28 Fix for issue #13
    Added version number to serial output
    [main.c]
2020-11-28 Small bug fix from testing
    [main.c]

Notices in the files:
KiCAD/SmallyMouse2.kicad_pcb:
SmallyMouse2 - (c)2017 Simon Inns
